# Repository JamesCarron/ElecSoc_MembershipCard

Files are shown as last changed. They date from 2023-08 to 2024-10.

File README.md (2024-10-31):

# ElecSoc Soldering Practice Card - JayceDesign - August 2024

## Introduction
The practice card is an oscillating circuit with a 555 timer. It blinks 2 sets of LEDs. The oscillating period is controlled with an RC circuit.

## Assembling the board
The board has 2 sets of components. Required and optional components. The required components are the minimum components needed to assemble to have a working card. The optional components are for soldering practice and to change the oscillator circuit. The required components are marked with an asterisk in the board.
To assemble the card, start with the bigger packages first. There are 4 different packages: 1206, 0805, 0603 and 0402. The bigger the number, the bigger the component, and easier to solder it will be. Start with the practice components first. Assemble first the optional 1206 resistors, then the 0805 LEDs. Then, move on to the practice network on the bottom left of the card. Then, start placing on the required components, from the largest package to the smallest. Lastly, solder on the 555 timer and the pin headers on the left.

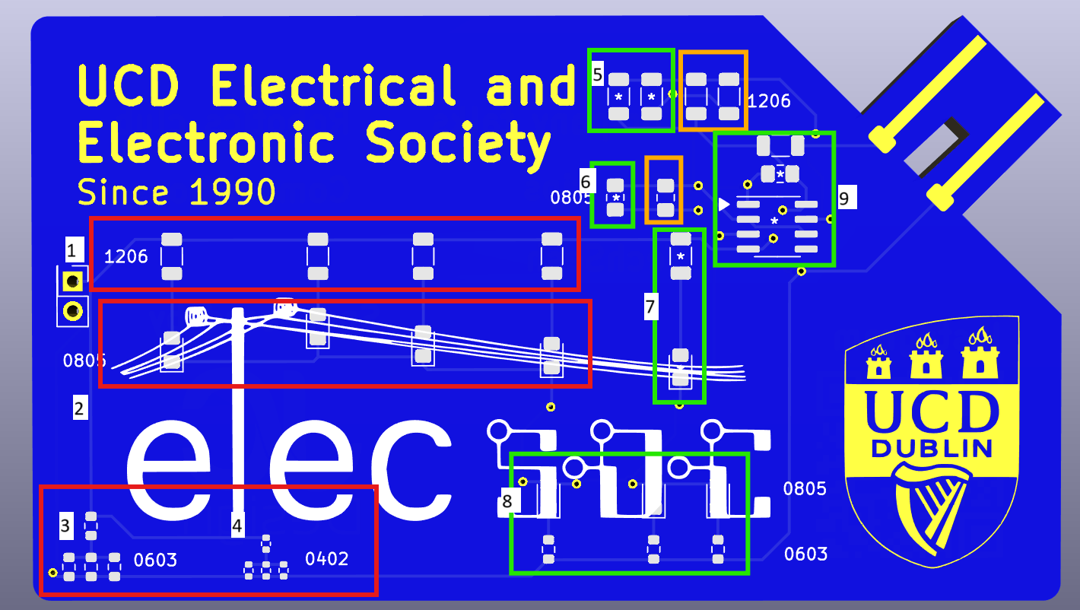
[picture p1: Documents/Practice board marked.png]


_The order of soldering is indicated above._

In red, the practice components. Green, components to assemble once comfortable with the process. Orange, extra components for tuning oscillating circuit. You don't need to solder all optional components, only as many as you need to feel comfortable with the soldering process.
## Testing
If properly assembled, when the card is powered, the LEDs will blink with a period of 1.5s. The practice network is a voltage divider. The voltage drop at the lower resistors should be 1.25V.
If you add the 5Ω resistor on the top right, you can slot the card in a USB port.
You can add the optional resistors for the oscillator circuit. This will reduce the period to about 0.8s. Adding only the extra capacitor will increase the period to 3.3s.

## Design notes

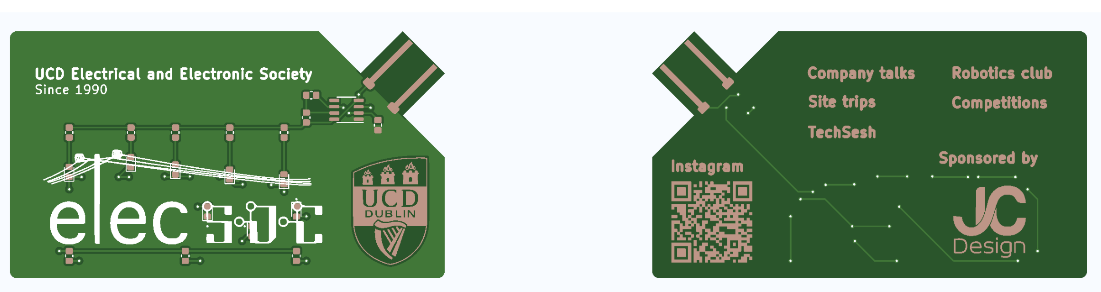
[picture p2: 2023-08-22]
Images/JLCPCB_Visual.png

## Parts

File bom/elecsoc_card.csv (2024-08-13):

Reference | Value | Datasheet | Footprint | Qty | DNP | MPN
C1,C2,C3 | 10u | https://www.mouser.ie/datasheet/2/585/MLCC-1837944.pdf | Capacitor_SMD:C_0805_2012Metric_Pad1.18x1.45mm_HandSolder | 3 |  | CL21A106KPFNNNF
D1,D2,D3,D4,D5 | WHITE | https://fscdn.rohm.com/en/products/databook/datasheet/opto/led/chip_mono/smlmn2wb1cw1(c)-e.pdf | LED_SMD:LED_0805_2012Metric_Pad1.15x1.40mm_HandSolder | 5 |  | SMLMN2WB1CW1
D6,D7,D8 | RED | https://www.mouser.ie/datasheet/2/180/IN_S85AT_Series_V1_1-2323391.pdf | LED_SMD:LED_0805_2012Metric_Pad1.15x1.40mm_HandSolder | 3 |  | IN-S85AT5UW
J2 | Conn_01x02_Pin | https://www.mouser.ie/datasheet/2/418/6/ENG_CD_826632_P-2048118.pdf | Connector_PinHeader_2.54mm:PinHeader_2x01_P2.54mm_Vertical | 1 |  | 826632-1
R1,R2,R18,R19 | 78k7 | https://www.mouser.ie/datasheet/2/447/PYu_RT_1_to_0_01_RoHS_L_15-3461507.pdf | Resistor_SMD:R_1206_3216Metric | 4 |  | RT1206FRE0778K7L
R3,R4,R5,R6,R7 | 3k | https://www.mouser.ie/datasheet/2/447/PYu_RT_1_to_0_01_RoHS_L_15-3461507.pdf | Resistor_SMD:R_1206_3216Metric | 5 |  | RT1206FRE073KL
R8,R9,R10,R12,R13,R14,R15 | 150 | https://www.vishay.com/doc?28705 | Resistor_SMD:R_0603_1608Metric | 7 |  | MCT06030C1500FP500
R11 | 5 | https://www.mouser.ie/datasheet/2/447/PYu_RT_1_to_0_01_RoHS_L_12-3003070.pdf | Resistor_SMD:R_1206_3216Metric | 1 |  | RT1206FRD075R1L
R16,R17,R20,R21 | 1k | https://www.vishay.com/doc?28705 | Resistor_SMD:R_0402_1005Metric | 4 |  | MCS04020C1001FE000
U1 | NA555D | http://www.ti.com/lit/ds/symlink/ne555.pdf | Package_SO:SOIC-8_3.9x4.9mm_P1.27mm | 1 |  | 621-NE555S-13

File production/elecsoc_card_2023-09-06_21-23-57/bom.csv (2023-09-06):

Designator | Footprint | Quantity | Value | LCSC Part #
C1, C2 | 0805 | 2 | 10u
D1, D2, D3, D4, D5 | 0805 | 5 | WHITE
D6, D7, D8 | 0805 | 3 | RED
J1 | USB_A_Male_inboard | 1 | Conn_01x02_Pin
R1, R2 | 0805 | 2 | 50k
R10, R8, R9 | 0805 | 3 | 150
R11 | 0805 | 1 | 5
R3, R4, R5, R6, R7 | 0805 | 5 | 390
U1 | SOIC-8_3.9x4.9mm_P1.27mm | 1 | NA555D

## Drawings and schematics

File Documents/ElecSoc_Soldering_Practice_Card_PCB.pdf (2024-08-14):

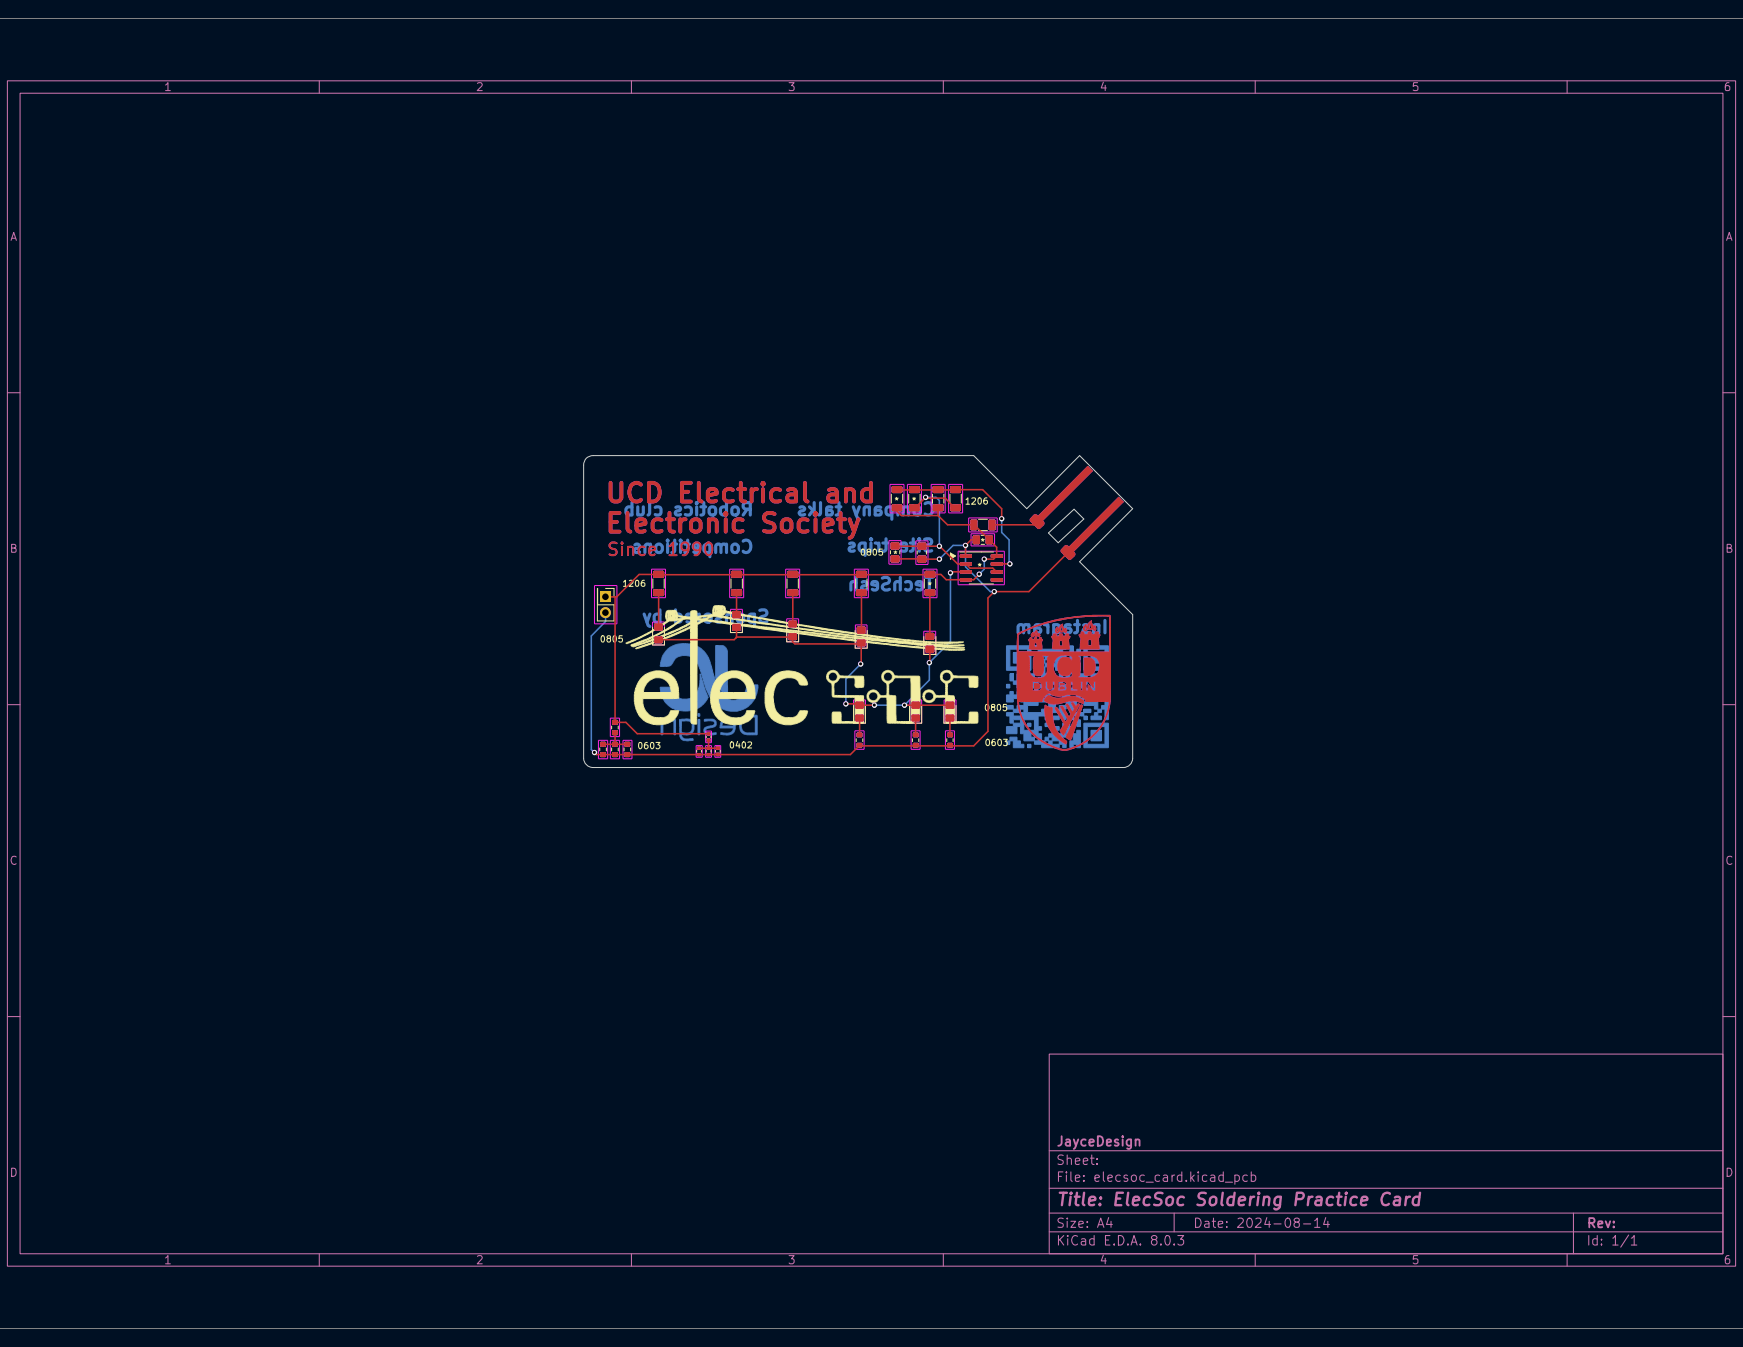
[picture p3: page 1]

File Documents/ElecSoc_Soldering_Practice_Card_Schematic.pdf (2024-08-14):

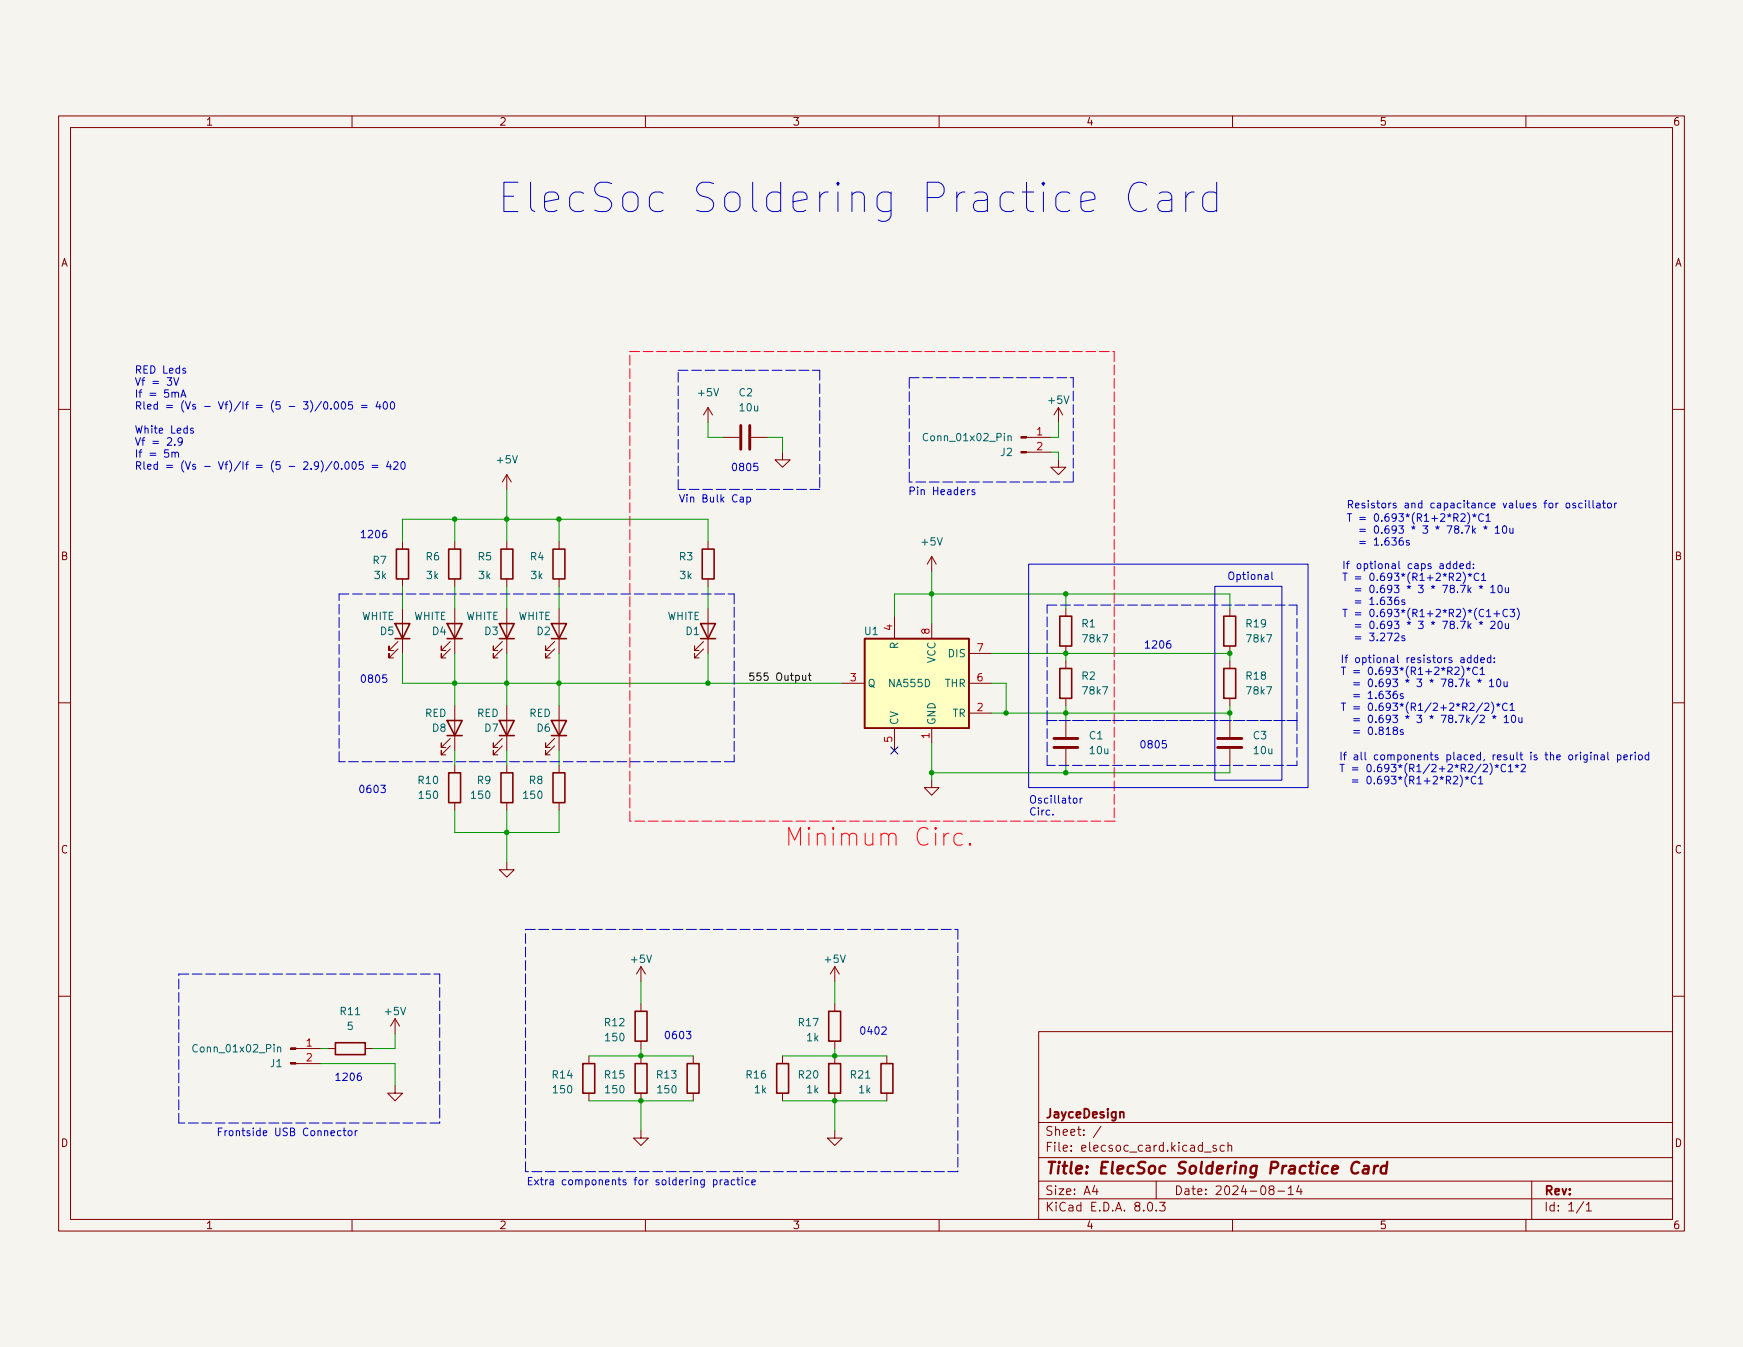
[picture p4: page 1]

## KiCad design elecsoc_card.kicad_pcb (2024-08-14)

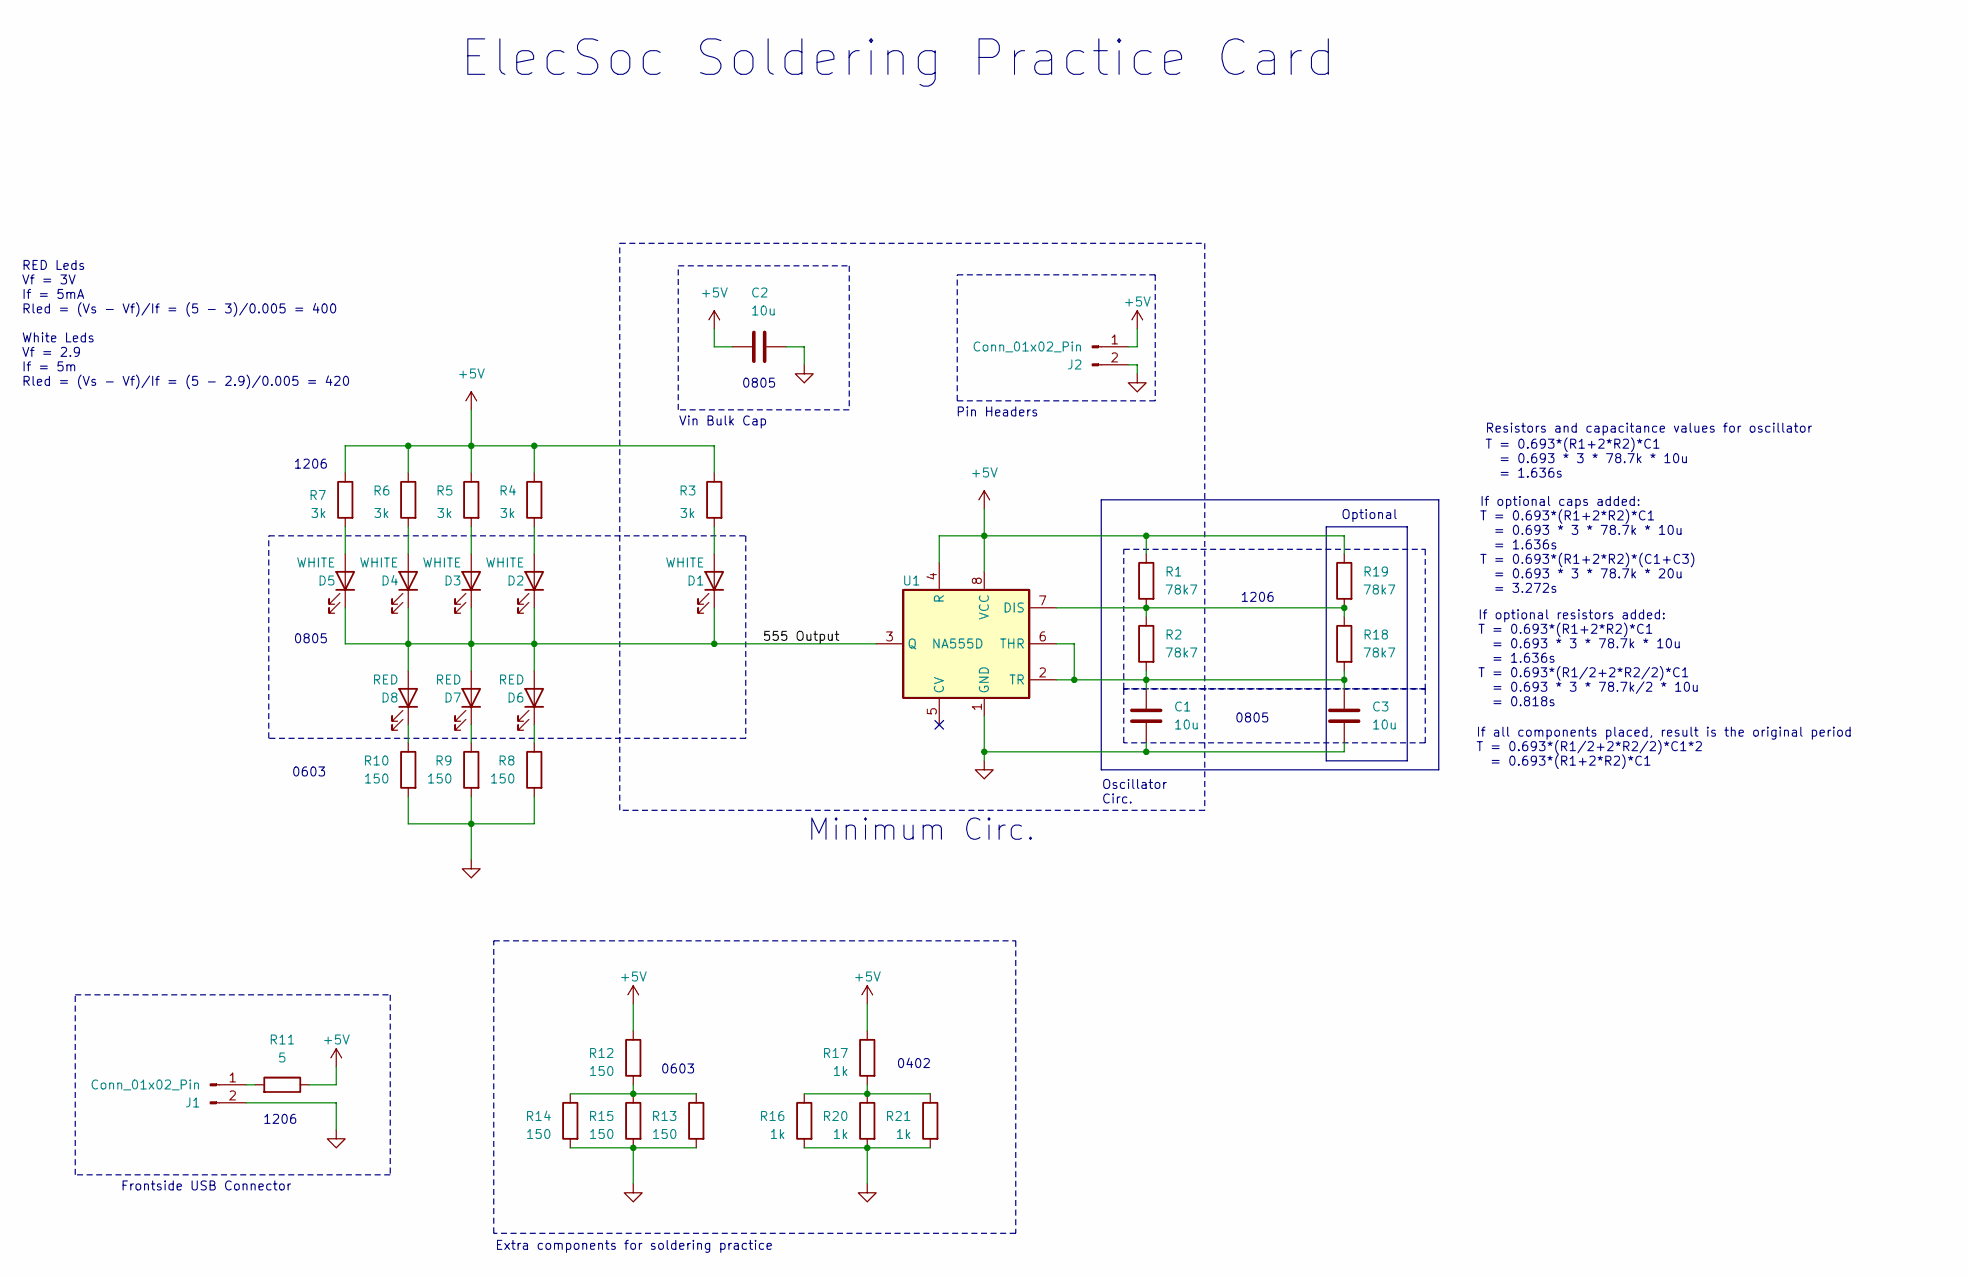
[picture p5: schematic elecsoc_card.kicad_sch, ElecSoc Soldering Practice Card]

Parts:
C1, C2, C3: 10u; C_0805_2012Metric_Pad1.18x1.45mm_HandSolder; MPN CL21A106KPFNNNF
D1, D2, D3, D4, D5: WHITE; LED_0805_2012Metric_Pad1.15x1.40mm_HandSolder; MPN SMLMN2WB1CW1
D6, D7, D8: RED; LED_0805_2012Metric_Pad1.15x1.40mm_HandSolder; MPN IN-S85AT5UW
J1: Conn_01x02_Pin; USB_A_Male_inboard
J2: Conn_01x02_Pin; PinHeader_2x01_P2.54mm_Vertical; MPN 826632-1
R1, R2, R18, R19: 78k7; R_1206_3216Metric; MPN RT1206FRE0778K7L
R3, R4, R5, R6, R7: 3k; R_1206_3216Metric; MPN RT1206FRE073KL
R8, R9, R10, R12, R13, R14, R15: 150; R_0603_1608Metric; MPN MCT06030C1500FP500
R11: 5; R_1206_3216Metric; MPN RT1206FRD075R1L
R16, R17, R20, R21: 1k; R_0402_1005Metric; MPN MCS04020C1001FE000
U1: NA555D; SOIC-8_3.9x4.9mm_P1.27mm; MPN 621-NE555S-13

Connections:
+5V: C2.1, J2.1, R1.1, R3.1, R4.1, R5.1, R6.1, R7.1, R11.1, R12.1, R17.1, R19.1, U1.4 (R), U1.8 (VCC)
/555 Output: D1.1 (K), D2.1 (K), D3.1 (K), D4.1 (K), D5.1 (K), D6.2 (A), D7.2 (A), D8.2 (A), U1.3 (Q)
GND: C1.2, C2.2, C3.2, J1.2, J2.2, R8.2, R9.2, R10.2, R13.2, R14.2, R15.2, R16.2, R20.2, R21.2, U1.1 (GND)
unnamed: D5.2 (A), R7.2
unnamed: D4.2 (A), R6.2
unnamed: D3.2 (A), R5.2
unnamed: D1.2 (A), R3.2
unnamed: D2.2 (A), R4.2
unnamed: D6.1 (K), R8.1
unnamed: D7.1 (K), R9.1
unnamed: D8.1 (K), R10.1
unnamed: J1.1, R11.2
unnamed: R12.2, R13.1, R14.1, R15.1
unnamed: R16.1, R17.2, R20.1, R21.1
unnamed: R1.2, R2.1, R18.1, R19.2, U1.7 (DIS)
unnamed: C1.1, C3.1, R2.2, R18.2, U1.2 (TR), U1.6 (THR)

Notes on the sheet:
Frontside USB Connector
Minimum Circ.
1206
RED Leds Vf = 3V If = 5mA Rled = (Vs - Vf)/If = (5 - 3)/0.005 = 400 White Leds Vf = 2.9 If = 5m Rled = (Vs - Vf)/If = (5 - 2.9)/0.005 = 420
If optional resistors added: T = 0.693*(R1+2*R2)*C1 = 0.693 * 3 * 78.7k * 10u = 1.636s T = 0.693*(R1/2+2*R2/2)*C1 = 0.693 * 3 * 78.7k/2 * 10u = 0.818s
0603
If optional caps added: T = 0.693*(R1+2*R2)*C1 = 0.693 * 3 * 78.7k * 10u = 1.636s T = 0.693*(R1+2*R2)*(C1+C3) = 0.693 * 3 * 78.7k * 20u = 3.272s
Pin Headers
0805
0402
Vin Bulk Cap
Oscillator Circ.
Resistors and capacitance values for oscillator
If all components placed, result is the original period T = 0.693*(R1/2+2*R2/2)*C1*2 = 0.693*(R1+2*R2)*C1
Optional
ElecSoc Soldering Practice Card
T = 0.693*(R1+2*R2)*C1 = 0.693 * 3 * 78.7k * 10u = 1.636s
Extra components for soldering practice

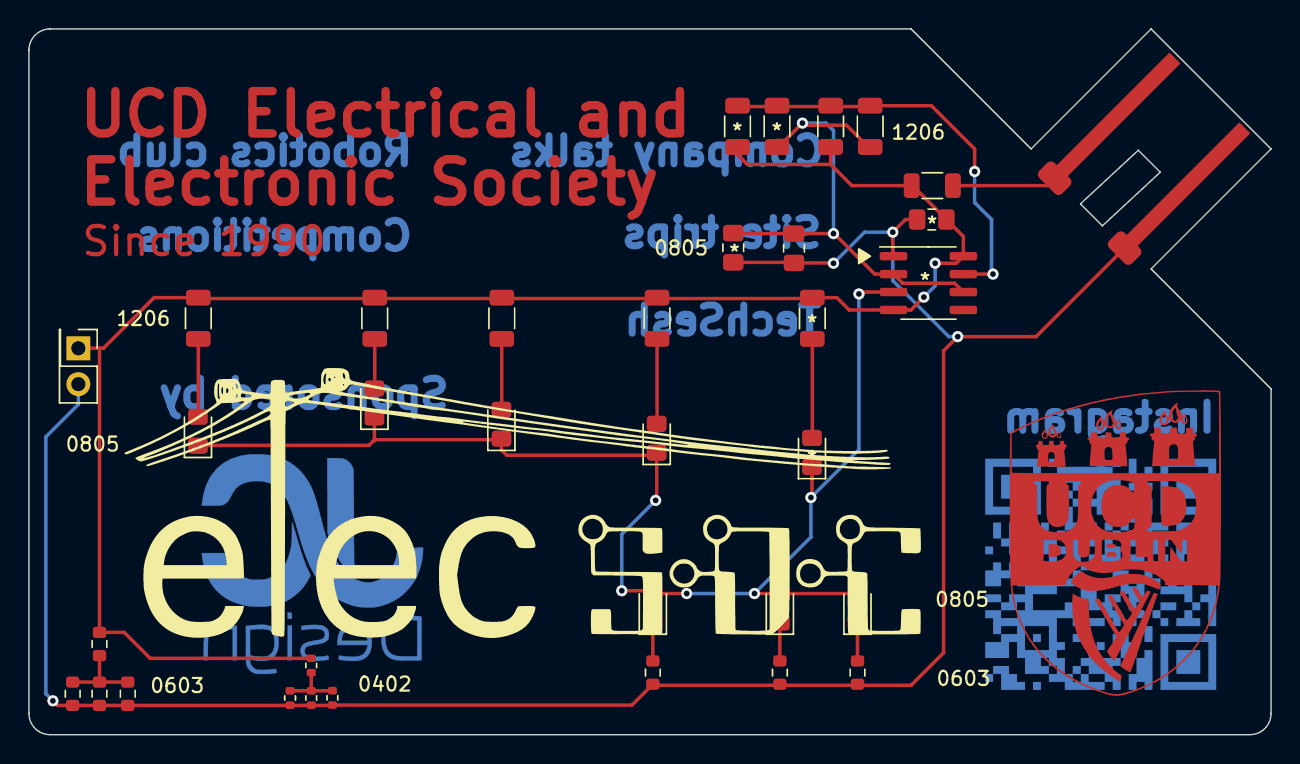
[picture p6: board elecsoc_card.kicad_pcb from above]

Board: 2 copper layers, 88.0 x 50.0 mm, 35 parts (0 on the bottom side), 16 nets.

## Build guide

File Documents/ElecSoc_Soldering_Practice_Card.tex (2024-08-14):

\documentclass{article}
\usepackage{graphicx} % Required for inserting images
\usepackage{float}
\usepackage{hyperref}
\usepackage{geometry}
\geometry{margin=2cm}

\title{ElecSoc Soldering Practice Card}
\author{JayceDesign}
\date{August 2024}

\begin{document}

\maketitle

\section{Introduction}
The practice card is an oscillating circuit with a 555 timer. It blinks 2 sets of LEDs. The oscillating period is controlled with an RC circuit.

\section{Assembling the board}
The board has 2 sets of components. Required and optional components. The required components are the minimum components needed to assemble to have a working card. The optional components are for soldering practice and to change the oscillator circuit. The required components are marked with an asterisk in the board.\\
To assemble the card, start with the bigger packages first. There are 4 different packages: 1206, 0805, 0603 and 0402. The bigger the number, the bigger the component, and easier to solder it will be. Start with the practice components first. Assemble first the optional 1206 resistors, then the 0805 LEDs. Then, move on to the practice network on the bottom left of the card. Then, start placing on the required components, from the largest package to the smallest. Lastly, solder on the 555 timer and the pin headers on the left.
\begin{figure} [H]
    \centering
    
    \caption{The order of soldering is indicated above.}
    \label{fig:enter-label}
\end{figure}
In red, the practice components. Green, components to assemble once comfortable with the process. Orange, extra components for tuning oscillating circuit. You don't need to solder all optional components, only as many as you need to feel comfortable with the soldering process.
\section{Testing}
If properly assembled, when the card is powered, the LEDs will blink with a period of 1.5s. The practice network is a voltage divider. The voltage drop at the lower resistors should be 1.25V.\\
If you add the 5$\Omega$ resistor on the top right, you can slot the card in a USB port.\\
You can add the optional resistors for the oscillator circuit. This will reduce the period to about 0.8s. Adding only the extra capacitor will increase the period to 3.3s.

\end{document}

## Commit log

2023-08-23 Changed R3-R7 to 390
    [elecsoc_card.kicad_sch]
2023-08-23 Added Mouser Part Order 230823
    [MouserOrder_230823.xlsx]
2023-09-06 Removed Items for Rev2, for Daniel to complete
    [elecsoc_card.kicad_pcb, elecsoc_card.kicad_sch]
2023-09-06 Routing added
    [elecsoc_card.kicad_pcb]
2023-09-06 Added silkscreen on usb port
    [elecsoc_card.kicad_pcb]
2023-09-06 Protection resistor and capacitor + cut for 3d printed part
    [elecsoc_card.kicad_pcb, elecsoc_card.kicad_sch]
2023-09-06 Caps added and resistors changed
    [elecsoc_card.kicad_sch]
2023-09-06 Changed resistors
    [elecsoc_card.kicad_sch]
2023-09-06 Manufacturer files
    [elecsoc_card-B_Cu.gbr, elecsoc_card-B_Mask.gbr, elecsoc_card-B_Paste.gbr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]
2023-09-06 No files in manufacturer folder
    [MouserOrder_230823.xlsx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]
2023-09-06 Rev2 Design Freeze
    [bom.csv, designators.csv, elecsoc_card.kicad_pcb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]
2023-09-06 As Ordered on JLCPCB - OrderRef: W202309070430314
    [bom.csv, designators.csv, elecsoc_card.kicad_pcb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]
2023-09-20 Updated PCB values from schematic, created interactive BOM, deleted unnecessary backups
2024-08-10 Added extra resistors for soldering practice
    [elecsoc_card.kicad_sch]
2024-08-10 Added extra parallel cap to see how the change in capacitance affects the period
    [elecsoc_card.kicad_sch]
2024-08-10 Added parallel resistors to change RC constant
    [elecsoc_card.kicad_sch]
2024-08-10 Values corrected
    [elecsoc_card.kicad_sch]
2024-08-10 Back to 80k
    [elecsoc_card.kicad_sch]
2024-08-10 New PCB design
    [elecsoc_card.kicad_pcb]
2024-08-10 Updated PCB
    [elecsoc_card.kicad_pcb]
2024-08-13 updated footprints, consolidated bom
    [elecsoc_card.kicad_sch]
2024-08-13 Package sizes updated
    [elecsoc_card.kicad_sch]
2024-08-13 Components placed and routed
    [elecsoc_card.kicad_pcb, elecsoc_card.kicad_sch]
2024-08-13 Silkscreen added
    [elecsoc_card.kicad_pcb]
2024-08-13 PCB finished plus gerbers
    [elecsoc_card-B_Adhesive.gbr, elecsoc_card-B_Cu.gbr, elecsoc_card-B_Mask.gbr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]
2024-08-13 Gerbers generated
    [elecsoc_card-B_Adhesive.gbr, elecsoc_card-B_Cu.gbr, elecsoc_card-B_Mask.gbr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]
2024-08-13 BOM generated
    [elecsoc_card.csv, elecsoc_card.kicad_sch]
2024-08-13 Interactive BOM created
2024-08-14 Added soldering instructions
    [elecsoc_card.kicad_pcb, elecsoc_card.kicad_sch]
